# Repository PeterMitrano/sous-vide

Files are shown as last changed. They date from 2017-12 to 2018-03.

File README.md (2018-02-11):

# Sous-Vide

My first PCB design project.

### Final Results!

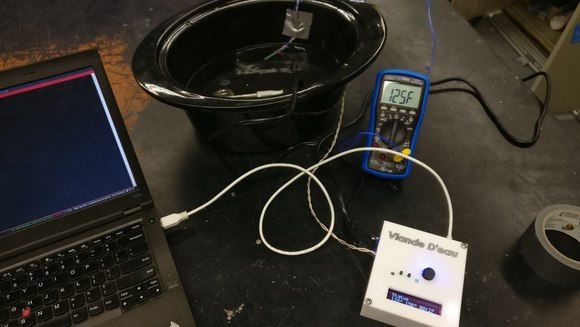
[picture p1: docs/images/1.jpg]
Tuning the temperature sensing

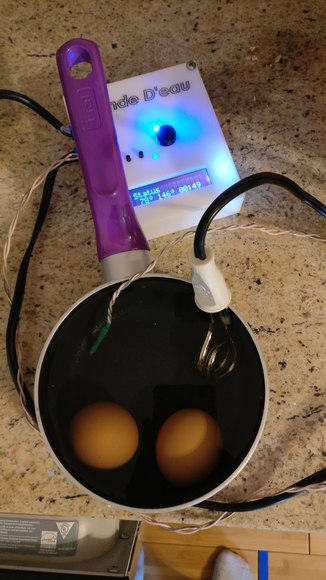
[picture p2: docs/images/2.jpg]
First Test with real food.

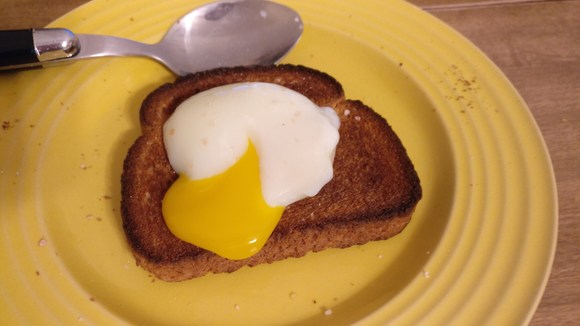
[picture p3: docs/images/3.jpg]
First Result. Perfect poached eggs!


### Materials

see [sous-vide_bom.csv](./kicad_proj/sous-vide_bom_0.3.csv)

### Schematic

see [sous-vide.sch](./kicad_proj/sous-vide.sch)

### PCB

see [sous-vide.kicad_pcb](./kicad_proj/sous-vide.kicad_pcb)

Mains power is scary. I used this to calculate trace width/clearance: http://www.desmith.net/NMdS/Electronics/TraceWidth.html

### Revision Notes

 - Hole size of screw terminals are too small. Should be 1.8542mm
 - Screw terminals are a bad idea, use IEC connector
 - Higher power heater
 - Buzzer/Dinger!
 - One wire for thermistor/heater
 - Something to stir the water around
 - Label on V+ and V- on heater are backwards (J1)
 - Button footprint is wrong

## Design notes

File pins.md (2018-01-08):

# Info on pin numbers

Arduino ESP has macros for D0-16 that map to the GPIO #

D0 -> GPIO 16 (Red LED)
D4 -> GPIO 2  (Blue LED on ESP)

### Pins I've tested with LED output

 - D0
 - D1
 - D2
 - D3
 - D4
 - D5
 - D6
 - D7
 - D8
 - RX
 - TX (no serial if you use this)
 - GPIO10 (SD3 on board)

### Pins that FAIL the LED test

 - TX, kinda because no serial
 - GPIO9, reserved for ESP
 - GPIO8, reserved for ESP
 - GPIO7, reserved for ESP
 - GPIO6, reserved for ESP

### Pins I've tested with Button Input

 - D0
 - D1
 - D2
 - D3
 - D4
 - D5
 - D6
 - D7

### Pins that FAIL the Button test

 - D8

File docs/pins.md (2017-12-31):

# Info on pin numbers

Arduino ESP has macros for D0-16 that map to the GPIO #

D0 -> GPIO 16 (Red LED)
D4 -> GPIO 2  (Blue LED on ESP)

### Pins I've tested with LED output

 - D0
 - D1
 - D2
 - D3
 - D4
 - D5
 - D6
 - D7
 - D8
 - D9 (RX on board, GPIO 3)
 - D10 (TX on board, GPIO 1, no serial if you use this)
 - GPIO10

### Pins that FAIL the LED test

 - D10, kinda because no serial
 - GPIO9, reserved for ESP
 - GPIO8, reserved for ESP
 - GPIO7, reserved for ESP
 - GPIO6, reserved for ESP

### Pins I've tested with Button Input

 - D0
 - D1
 - D2
 - D3
 - D4
 - D5
 - D6
 - D7

### Pins that FAIL the Button test

 - D8

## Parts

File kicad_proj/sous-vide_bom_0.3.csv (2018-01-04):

Component | Description | Part | References | Value | Footprint | Quantity Per PCB | Datasheet | Part # | Field8 | Field4 | Field7 | Field6 | Field5
1 | Unpolarized capacitor | C | C1 | 200nF | C_Disc_D4.3mm_W1.9mm_P5.00mm | 1
2 | Unpolarized capacitor | C | C2 | 330uF | CP_Radial_D8.0mm_P3.50mm | 1
3 | Diode | D | D1 D2 D4 | D | D_DO-35_SOD27_P7.62mm_Horizontal | 3 | https://www.fairchildsemi.com/datasheets/1N/1N914.pdf | 1N4148FS-ND
4 | LED generic | LED | D3 D5 D6 | LED | LED_D5.0mm | 3 | http://www.lumex.com/content/files/ProductAttachment/SSL-LX5093ID.pdf | 67-1105-ND
5 | Fuse, generic | Fuse | F1 | Fuse | Fuse_Holder_65600001009 | 1
6 | Generic connector, single row, 01x02 | Conn_01x02 | J3 | Conn_01x02 | Pin_Header_Straight_1x02_Pitch2.54mm | 1
7 | Generic connector, single row, 01x02 | Conn_01x02 | J1 | Heater | NC6-P108-02 | 1
8 | Generic connector, single row, 01x02 | Conn_01x02 | J4 J5 | Jumper | Pin_Header_Straight_1x02_Pitch2.54mm | 2
9 | Generic screw terminal, single row, 01x02 | Screw_Terminal_01x02 | J2 | Power | NC6-P108-02 | 1
10 | 40V Vce, 0.2A Ic, NPN, Small Signal Transistor, TO-92 | 2N3904 | Q1 | 2N3904 | TO-92_Molded_Narrow | 1 | https://www.fairchildsemi.com/datasheets/MM/MMBT3904.pdf
11 | Generic Resistor Package | RESISTOR0402 | R7 | 1.1k | R_Axial_DIN0207_L6.3mm_D2.5mm_P10.16mm_Horizontal | 1
12 | Generic Resistor Package | RESISTOR0402 | R1 | 110 | R_Axial_DIN0207_L6.3mm_D2.5mm_P10.16mm_Horizontal | 1
13 | Generic Resistor Package | RESISTOR0402 | R2 R6 | 11k | R_Axial_DIN0207_L6.3mm_D2.5mm_P10.16mm_Horizontal | 2
14 | Generic Resistor Package | RESISTOR0402 | R4 R5 | 43 | R_Axial_DIN0207_L6.3mm_D2.5mm_P10.16mm_Horizontal | 2
15 | Generic Resistor Package | RESISTOR0402 | R3 | 430 | R_Axial_DIN0207_L6.3mm_D2.5mm_P10.16mm_Horizontal | 1
16 | Push button switch, generic, symbol, four pins | SW_Push_Dual | SW1 SW2 | SW_Push_Dual | SW_TH_Tactile_Omron_B3F-10xx | 2 | http://omronfs.omron.com/en_US/ecb/products/pdf/en-b3f.pdf | SW400-ND
17 |  | G5LE | U1 | G5LE | Relay_SPDT_OMRON-G5LE-1 | 1 | https://media.digikey.com/pdf/Data%20Sheets/Omron%20PDFs/G5LE-E_G.pdf
18 |  | LCD_Backpack | U5 | LCD_Backpack | Pin_Header_Straight_1x05_Pitch2.54mm | 1
19 |  | P090S-04F20BR10K | U4 | P090S | P090S-THT_MNT | 1 | P090S-04F20BR10K |  | TT Electronics/BI | Good | None | 0.40 USD | Res Conductive Plastic POT 10K Ohm 20% 0.03W 1(Elec)/1(Mech)Turn 6mm (11.4 X 12.65 X 23mm) Pin Bracket Mount/Through ...
20 |  | RAC01 | U2 | RAC01 | RAC01-05SC | 1 | https://www.recom-power.com/pdf/Powerline-AC-DC/RAC01_02-SC.pdf
21 |  | node_mcu1.0 | U3 | node_mcu1.0 | NodeMCU_1_0 | 1
Component Groups: | 21
Component Count: | 29
Fitted Components: | 29
Number of PCBs: | 1
Total components: | 29
Schematic Version: | 0.3
Schematic Date: | 2018-01-01
BoM Date: | Thu 04 Jan 2018 14:43:18 EST
Schematic Source: | /home/peter/Projects/sous-vide/sous-vide.sch
KiCad Version: | Eeschema 4.0.7-e2-6376~58~ubuntu16.04.1

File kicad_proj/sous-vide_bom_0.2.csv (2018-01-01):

Component | Description | Part | References | Value | Footprint | Quantity Per PCB | Datasheet | Part # | Field8 | Field4 | Field7 | Field6 | Field5
1 | Unpolarized capacitor | C | C1 | C | C_Disc_D4.3mm_W1.9mm_P5.00mm | 1
2 | Diode | D | D1 D2 D4 | D | D_DO-35_SOD27_P7.62mm_Horizontal | 3 | https://www.fairchildsemi.com/datasheets/1N/1N914.pdf | 1N4148FS-ND
3 | LED generic | LED | D3 D5 D6 | LED | LED_D5.0mm | 3 | http://www.lumex.com/content/files/ProductAttachment/SSL-LX5093ID.pdf | 67-1105-ND
4 | Generic connector, single row, 01x02 | Conn_01x02 | J1 | Conn_01x02 | NC6-P108-02 | 1
5 | Generic screw terminal, single row, 01x02 | Screw_Terminal_01x02 | J2 | Conn_01x02 | NC6-P108-02 | 1
6 | Generic connector, single row, 01x02 | Conn_01x02 | J3 | Conn_01x02 | Pin_Header_Straight_1x02_Pitch2.54mm | 1
7 | 40V Vce, 0.2A Ic, NPN, Small Signal Transistor, TO-92 | 2N3904 | Q1 | 2N3904 | TO-92_Molded_Narrow | 1 | https://www.fairchildsemi.com/datasheets/MM/MMBT3904.pdf
8 | Generic Resistor Package | RESISTOR0402 | R7 | 1.1k | R_Axial_DIN0207_L6.3mm_D2.5mm_P10.16mm_Horizontal | 1
9 | Generic Resistor Package | RESISTOR0402 | R1 | 110 | R_Axial_DIN0207_L6.3mm_D2.5mm_P10.16mm_Horizontal | 1
10 | Generic Resistor Package | RESISTOR0402 | R2 R6 | 11k | R_Axial_DIN0207_L6.3mm_D2.5mm_P10.16mm_Horizontal | 2
11 | Generic Resistor Package | RESISTOR0402 | R4 R5 | 43 | R_Axial_DIN0207_L6.3mm_D2.5mm_P10.16mm_Horizontal | 2
12 | Push button switch, generic, symbol, four pins | SW_Push_Dual | SW1 SW2 | SW_Push_Dual | SW_TH_Tactile_Omron_B3F-10xx | 2 | http://omronfs.omron.com/en_US/ecb/products/pdf/en-b3f.pdf | SW400-ND
13 |  | G5LE | U1 | G5LE | Relay_SPDT_OMRON-G5LE-1 | 1 | https://media.digikey.com/pdf/Data%20Sheets/Omron%20PDFs/G5LE-E_G.pdf
14 |  | LCD_Backpack | U5 | LCD_Backpack | Pin_Header_Straight_1x05_Pitch2.54mm | 1
15 |  | P090S-04F20BR10K | U4 | P090S | P090S-THT_MNT | 1 | P090S-04F20BR10K |  | TT Electronics/BI | Good | None | 0.40 USD | Res Conductive Plastic POT 10K Ohm 20% 0.03W 1(Elec)/1(Mech)Turn 6mm (11.4 X 12.65 X 23mm) Pin Bracket Mount/Through ...
16 |  | RAC01 | U2 | RAC01 | RAC01-05SC | 1 | https://www.recom-power.com/pdf/Powerline-AC-DC/RAC01_02-SC.pdf
17 |  | node_mcu1.0 | U3 | node_mcu1.0 | NodeMCU_1_0 | 1
Component Groups: | 17
Component Count: | 24
Fitted Components: | 24
Number of PCBs: | 1
Total components: | 24
Schematic Version: | 0.2
Schematic Date: | 2017-12-28
BoM Date: | Mon 01 Jan 2018 16:54:34 EST
Schematic Source: | /home/peter/Projects/sous-vide/sous-vide.sch
KiCad Version: | Eeschema 4.0.7-e2-6376~58~ubuntu16.04.1

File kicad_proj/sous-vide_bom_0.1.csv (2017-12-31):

Component | Description | Part | References | Value | Footprint | Quantity Per PCB | Datasheet | Part # | Field8 | Field4 | Field7 | Field6 | Field5
1 | Diode | D | D3 D4 D5 | D | D_DO-35_SOD27_P7.62mm_Horizontal | 3 | https://www.fairchildsemi.com/datasheets/1N/1N914.pdf | 1N4148FS-ND
2 | LED generic | LED | D1 D2 D6 | LED | LED_D5.0mm | 3 | http://www.lumex.com/content/files/ProductAttachment/SSL-LX5093ID.pdf | 67-1105-ND
3 | Generic screw terminal, single row, 01x02 | Screw_Terminal_01x02 | J2 | Conn_01x02 | NC6-P108-02 | 1
4 | Generic connector, single row, 01x02 | Conn_01x02 | J3 | Conn_01x02 | Pin_Header_Straight_1x02_Pitch2.54mm | 1
5 | Generic connector, single row, 01x02 | Conn_01x02 | J5 | Conn_01x02 | NC6-P108-02 | 1
6 | 40V Vce, 0.2A Ic, NPN, Small Signal Transistor, TO-92 | 2N3904 | Q1 | 2N3904 | TO-92_Molded_Narrow | 1 | https://www.fairchildsemi.com/datasheets/MM/MMBT3904.pdf
7 | Generic Resistor Package | RESISTOR0402 | R8 | 110 | R_Axial_DIN0204_L3.6mm_D1.6mm_P7.62mm_Horizontal | 1
8 | Generic Resistor Package | RESISTOR0402 | R5 R7 | 11k | R_Axial_DIN0204_L3.6mm_D1.6mm_P7.62mm_Horizontal | 2
9 | Generic Resistor Package | RESISTOR0402 | R6 | 1k | R_Axial_DIN0204_L3.6mm_D1.6mm_P7.62mm_Horizontal | 1
10 | Generic Resistor Package | RESISTOR0402 | R3 R4 | 41 | R_Axial_DIN0204_L3.6mm_D1.6mm_P7.62mm_Horizontal | 2
11 | Push button switch, generic, symbol, four pins | SW_Push_Dual | SW1 SW2 | SW_Push_Dual | SW_TH_Tactile_Omron_B3F-10xx | 2 | http://omronfs.omron.com/en_US/ecb/products/pdf/en-b3f.pdf | SW400-ND
12 |  | G5LE | U3 | G5LE | Relay_SPDT_OMRON-G5LE-1 | 1 | https://media.digikey.com/pdf/Data%20Sheets/Omron%20PDFs/G5LE-E_G.pdf
13 |  | LCD_Backpack | U4 | LCD_Backpack | Pin_Header_Straight_1x05_Pitch2.54mm | 1
14 |  | P090S-04F20BR10K | U5 | P090S-04F20BR10K | TRIM_P090S-04F20BR10K | 1 | P090S-04F20BR10K |  | TT Electronics/BI | Good | None | 0.40 USD | Res Conductive Plastic POT 10K Ohm 20% 0.03W 1(Elec)/1(Mech)Turn 6mm (11.4 X 12.65 X 23mm) Pin Bracket Mount/Through ...
15 |  | RAC01 | U2 | RAC01 | RAC01-05SC | 1 | https://www.recom-power.com/pdf/Powerline-AC-DC/RAC01_02-SC.pdf
16 |  | node_mcu1.0 | U1 | node_mcu1.0 | NodeMCU_1_0 | 1
Component Groups: | 16
Component Count: | 23
Fitted Components: | 23
Number of PCBs: | 1
Total components: | 23
Schematic Version: | 0.1
Schematic Date: | 2017-12-28
BoM Date: | Sat 30 Dec 2017 17:26:24 EST
Schematic Source: | /home/peter/Projects/sous-vide/sous-vide.sch
KiCad Version: | Eeschema 4.0.7-e2-6376~58~ubuntu16.04.1

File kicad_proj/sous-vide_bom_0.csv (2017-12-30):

Component | Description | Part | References | Value | Footprint | Quantity Per PCB | Datasheet | Part # | URL
1 | Diode | D | D3 D4 D5 | D |  | 3 | https://www.fairchildsemi.com/datasheets/1N/1N914.pdf | 1N4148FS-ND
2 | LED generic | LED | D1 D2 D6 | LED |  | 3 | http://www.lumex.com/content/files/ProductAttachment/SSL-LX5093ID.pdf | 67-1105-ND
3 | Generic screw terminal, single row, 01x02 | Screw_Terminal_01x02 | J2 | Conn_01x02 |  | 1
4 | Generic connector, single row, 01x04 | Conn_01x04 | J3 | Conn_01x04 |  | 1
5 | 40V Vce, 0.2A Ic, NPN, Small Signal Transistor, TO-92 | 2N3904 | Q1 | 2N3904 | TO-92_Molded_Narrow | 1 | https://www.fairchildsemi.com/datasheets/MM/MMBT3904.pdf
6 | Generic Resistor Package | RESISTOR0402 | R3 R4 R8 | 100 | 0402 | 3
7 | Generic Resistor Package | RESISTOR0402 | R1 R2 R5 R7 | 10k | 0402 | 4 | http://www.yageo.com/documents/recent/Yageo%20LR_CFR_2013.pdf
8 | Generic Resistor Package | RESISTOR0402 | R6 | 1k | 0402 | 1
9 | Potentiometer | POT | RV1 | POT |  | 1 | http://www.vishay.com/docs/51036/p16pa16.pdf
10 | Push button switch, generic, symbol, four pins | SW_Push_Dual | SW1 SW2 | SW_Push_Dual |  | 2 | http://omronfs.omron.com/en_US/ecb/products/pdf/en-b3f.pdf | SW400-ND
11 |  | G5LE | U3 | G5LE |  | 1 | https://media.digikey.com/pdf/Data%20Sheets/Omron%20PDFs/G5LE-E_G.pdf
12 | LCD Backpack | LCD_Backpack | U4 | LCD_Backpack |  | 1 |  |  | https://www.adafruit.com/product/292
13 |  | RAC01 | U2 | RAC01 |  | 1 | https://www.recom-power.com/pdf/Powerline-AC-DC/RAC01_02-SC.pdf
14 |  | node_mcu1.0 | U1 | node_mcu1.0 |  | 1
Component Groups: | 14
Component Count: | 24
Fitted Components: | 24
Number of PCBs: | 1
Total components: | 24
Schematic Version: | 0
Schematic Date: | 2017-12-28
BoM Date: | Thu 28 Dec 2017 18:33:16 EST
Schematic Source: | /home/peter/Projects/sous-vide/sous-vide.sch
KiCad Version: | Eeschema 4.0.7-e2-6376~58~ubuntu16.04.1

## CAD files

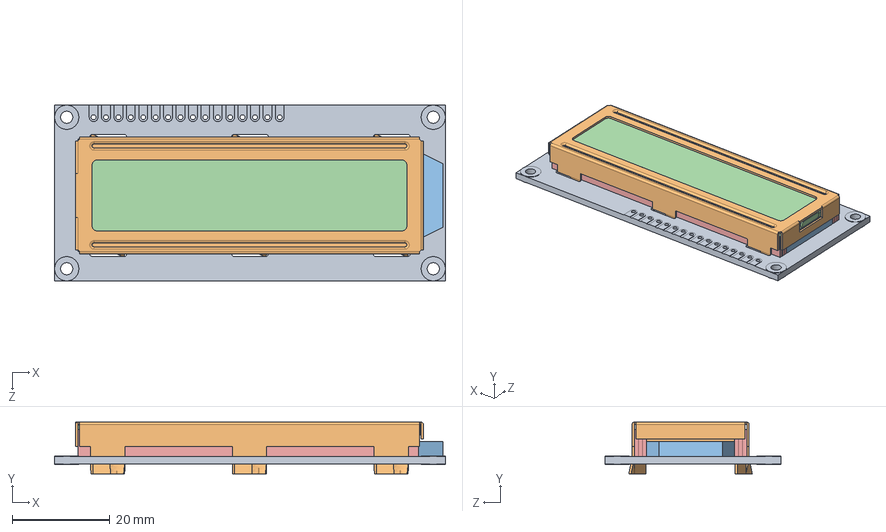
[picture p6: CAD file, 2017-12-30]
CAD/16x2_LCD_Display/DFRobot_1602_LCD.SLDASM
80.0 x 10.6 x 36.0 mm
LCD_PCB
metal_casing
LCDbacklight
LCD
conductors x 2

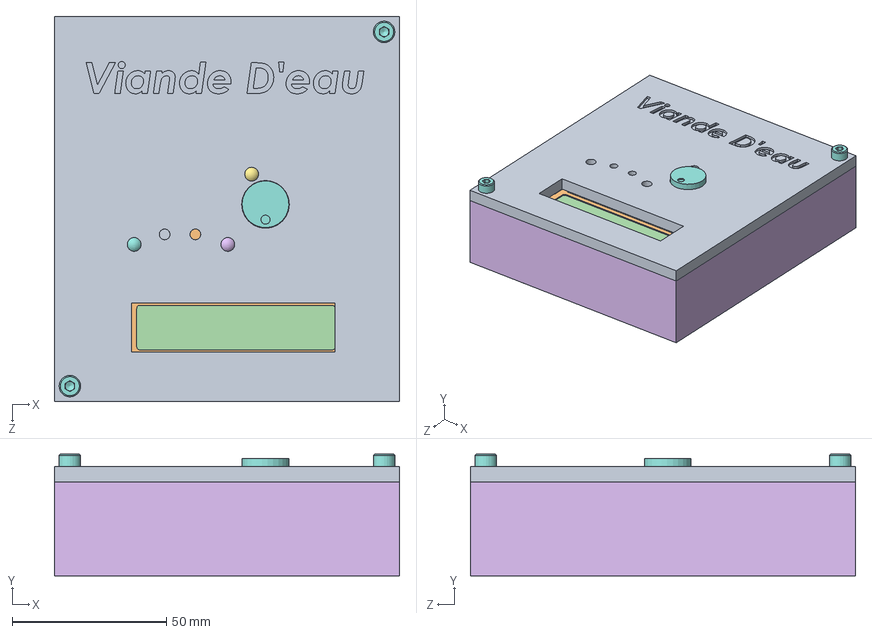
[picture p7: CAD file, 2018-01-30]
CAD/sous-vide.SLDASM
112.0 x 39.6 x 125.0 mm
LCD_PCB
metal_casing
LCDbacklight
LCD
conductors x 2
case_bottom
lcd_backpack
socket head cap screw_am x 6
case_top
Pcb
NodeMCU_1_002_
Fuse_Holder_65600001009_
RAC01-05SC_
D_DO-35_SOD27_P7.62mm_Horizontal002_
TO-92_Molded_Narrow_
LED_D5.0mm_
B3F_1002_
B3F_1002_001
Pin_Header_Straight_1x02_Pitch254mm_
D_DO-35_SOD27_P7.62mm_Horizontal002_001
D_DO-35_SOD27_P7.62mm_Horizontal002_002
LED_D5.0mm_001
LED_D5.0mm_002
Pin_Header_Straight_1x05_Pitch254mm_
R_Axial_DIN0207_L63mm_D25mm_P1016mm_Horizontal_
R_Axial_DIN0207_L63mm_D25mm_P1016mm_Horizontal_001
R_Axial_DIN0207_L63mm_D25mm_P1016mm_Horizontal_002
R_Axial_DIN0207_L63mm_D25mm_P1016mm_Horizontal_003
R_Axial_DIN0207_L63mm_D25mm_P1016mm_Horizontal_004
P090S_
C_Disc_D43mm_W19mm_P500mm_
R_Axial_DIN0207_L63mm_D25mm_P1016mm_Horizontal_005
Pin_Header_Straight_1x02_Pitch254mm_001
Pin_Header_Straight_1x02_Pitch254mm_002
nc6-p108-02_
nc6-p108-02_001
CP_Radial_D80mm_P350mm_
R_Axial_DIN0207_L63mm_D25mm_P1016mm_Horizontal_006
g5le-1-e_5dc_
fancy_knob_for_cnc
button_holder

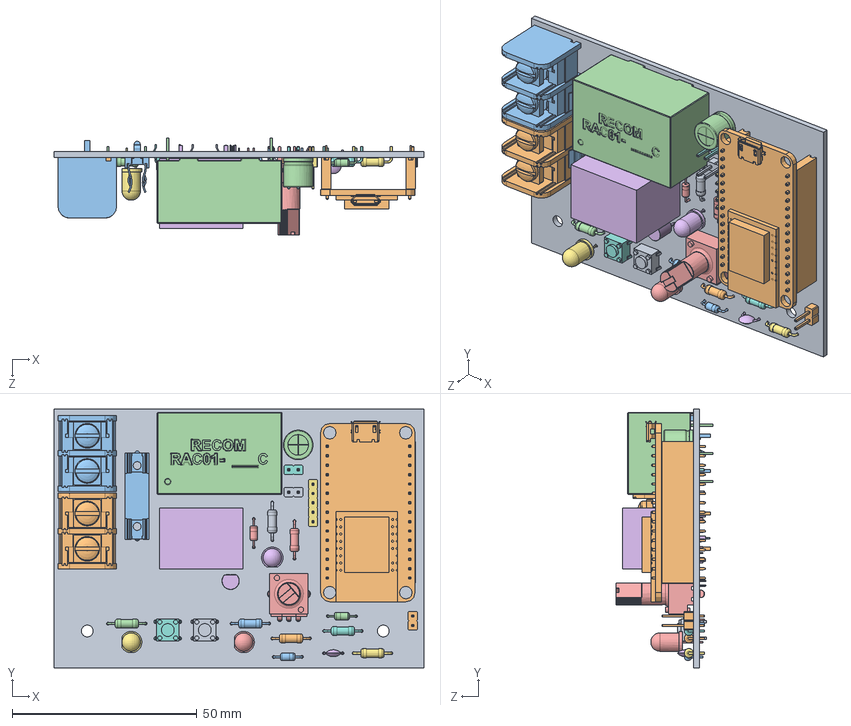
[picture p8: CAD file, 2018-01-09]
CAD/board/board.SLDASM
100.0 x 70.0 x 26.3 mm
Pcb
NodeMCU_1_002_
Fuse_Holder_65600001009_
RAC01-05SC_
D_DO-35_SOD27_P7.62mm_Horizontal002_
TO-92_Molded_Narrow_
LED_D5.0mm_
B3F_1002_
B3F_1002_001
Pin_Header_Straight_1x02_Pitch254mm_
D_DO-35_SOD27_P7.62mm_Horizontal002_001
D_DO-35_SOD27_P7.62mm_Horizontal002_002
LED_D5.0mm_001
LED_D5.0mm_002
Pin_Header_Straight_1x05_Pitch254mm_
R_Axial_DIN0207_L63mm_D25mm_P1016mm_Horizontal_
R_Axial_DIN0207_L63mm_D25mm_P1016mm_Horizontal_001
R_Axial_DIN0207_L63mm_D25mm_P1016mm_Horizontal_002
R_Axial_DIN0207_L63mm_D25mm_P1016mm_Horizontal_003
R_Axial_DIN0207_L63mm_D25mm_P1016mm_Horizontal_004
P090S_
C_Disc_D43mm_W19mm_P500mm_
R_Axial_DIN0207_L63mm_D25mm_P1016mm_Horizontal_005
Pin_Header_Straight_1x02_Pitch254mm_001
Pin_Header_Straight_1x02_Pitch254mm_002
nc6-p108-02_
nc6-p108-02_001
CP_Radial_D80mm_P350mm_
R_Axial_DIN0207_L63mm_D25mm_P1016mm_Horizontal_006
g5le-1-e_5dc_

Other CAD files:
CAD/NodeMCU/asm_pin_1.sldasm
CAD/NodeMCU/asm_pin_7.sldasm
CAD/NodeMCU/asm_pin (1) (1)_13.sldasm
CAD/NodeMCU/asm_pin (1) (1).sldasm
CAD/NodeMCU/asm_pin_3.sldasm
CAD/NodeMCU/asm_pin (1) (1)_4.sldasm
CAD/NodeMCU/asm_pin_9.sldasm
CAD/NodeMCU/asm_pin_4.sldasm
CAD/NodeMCU/asm_pin (1) (1)_14.sldasm
CAD/NodeMCU/Placa Base.sldasm
CAD/NodeMCU/asm_pin (1) (1)_2.sldasm
CAD/NodeMCU/asm_pin (1) (1)_11.sldasm
CAD/NodeMCU/asm_pin_2.sldasm
CAD/NodeMCU/asm_pin (1) (1)_12.sldasm
CAD/NodeMCU/asm_pin (1) (1)_1.sldasm
CAD/16x2_LCD_Display/LCD.SLDPRT
CAD/16x2_LCD_Display/LCD_PCB.SLDPRT
CAD/16x2_LCD_Display/LCDbacklight.SLDPRT
CAD/16x2_LCD_Display/conductors.SLDPRT
CAD/16x2_LCD_Display/metal_casing.SLDPRT
CAD/NodeMCU/Component41.sldprt
CAD/NodeMCU/Cuerpo Microprocesador v1.sldprt
CAD/NodeMCU/ESP8266 v7.SLDASM
CAD/NodeMCU/ESP8266 v7.f3d
CAD/NodeMCU/ESP8266 v7.sldprt
CAD/NodeMCU/Led RGB v4.f3d
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

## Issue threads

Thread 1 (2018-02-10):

Notes for future revisions

PeterMitrano, 2018-02-10:
- higher wattage heater
 - fix button footprints
 - better terminals to connect stuff
 - one wire for thermistor/heater
 - something to move the water
 - buzzer
 - indicate when setpoint is reached

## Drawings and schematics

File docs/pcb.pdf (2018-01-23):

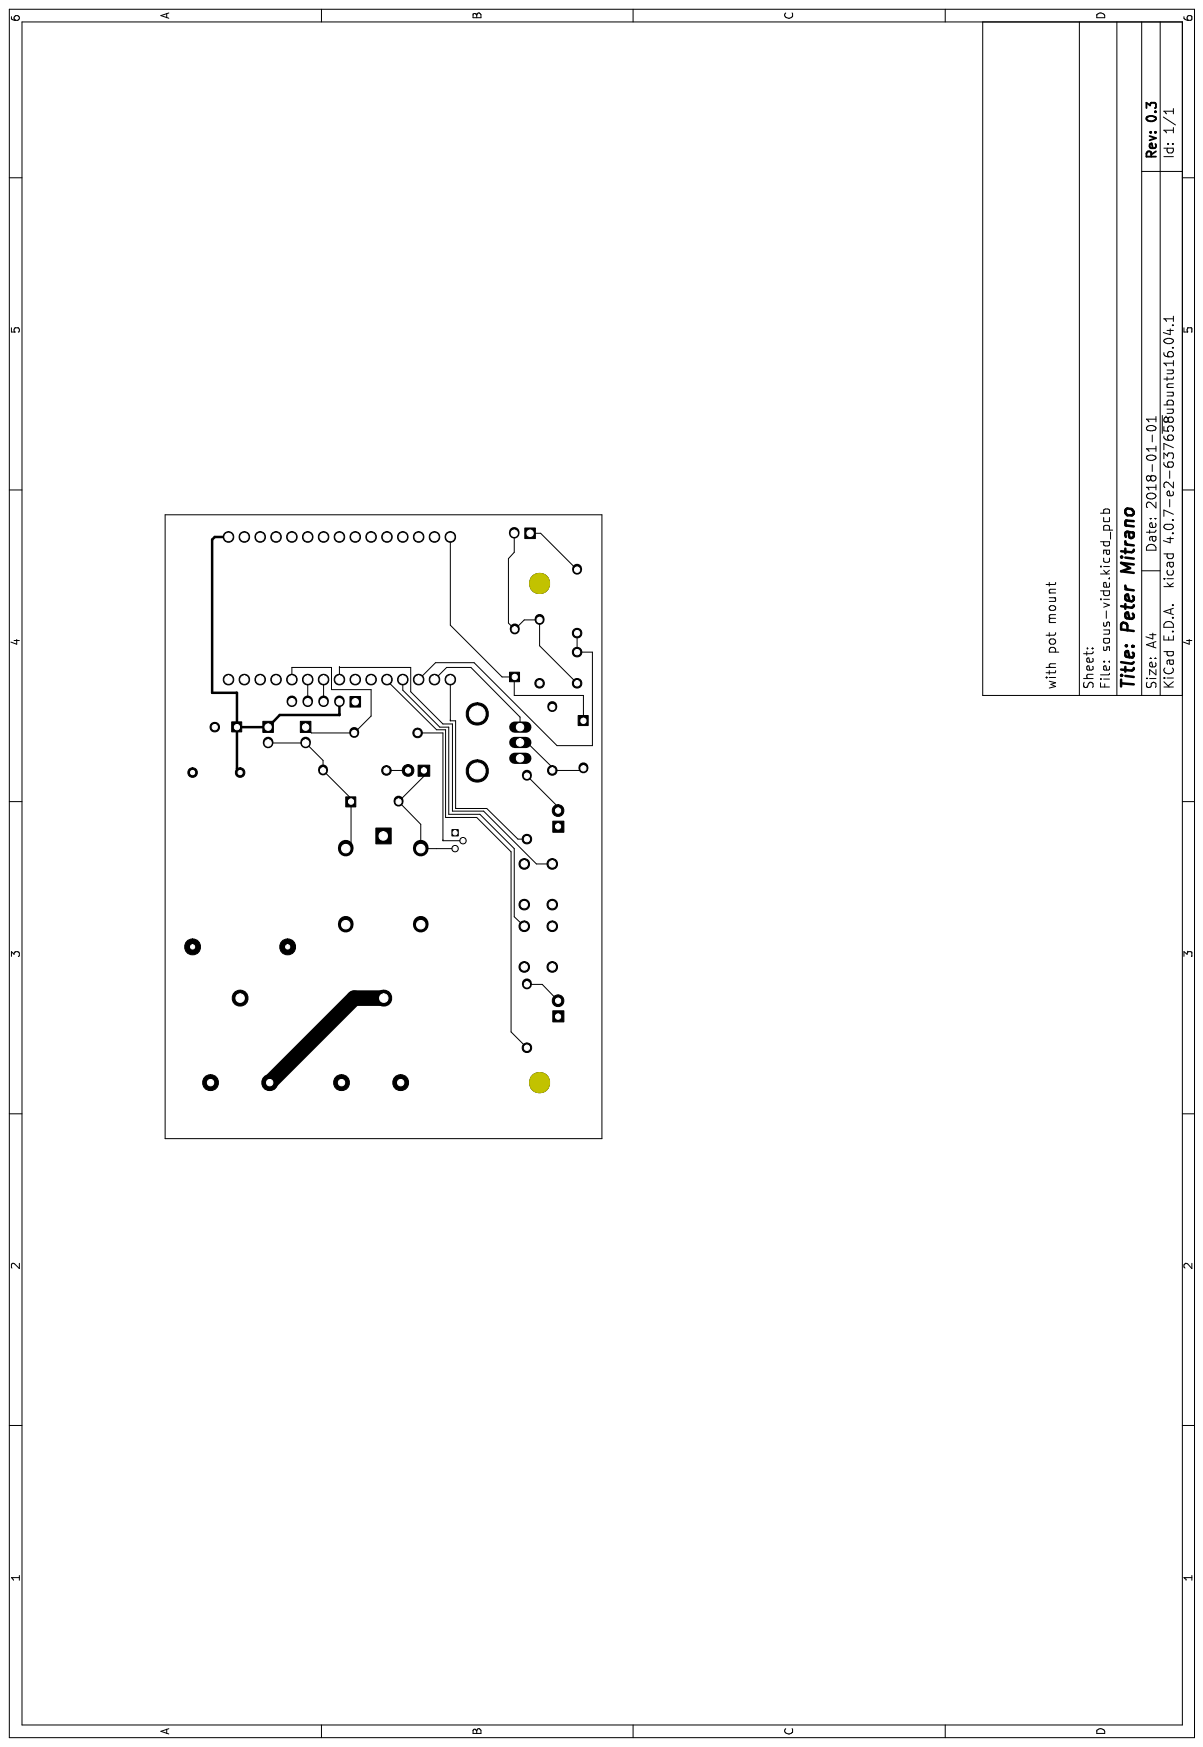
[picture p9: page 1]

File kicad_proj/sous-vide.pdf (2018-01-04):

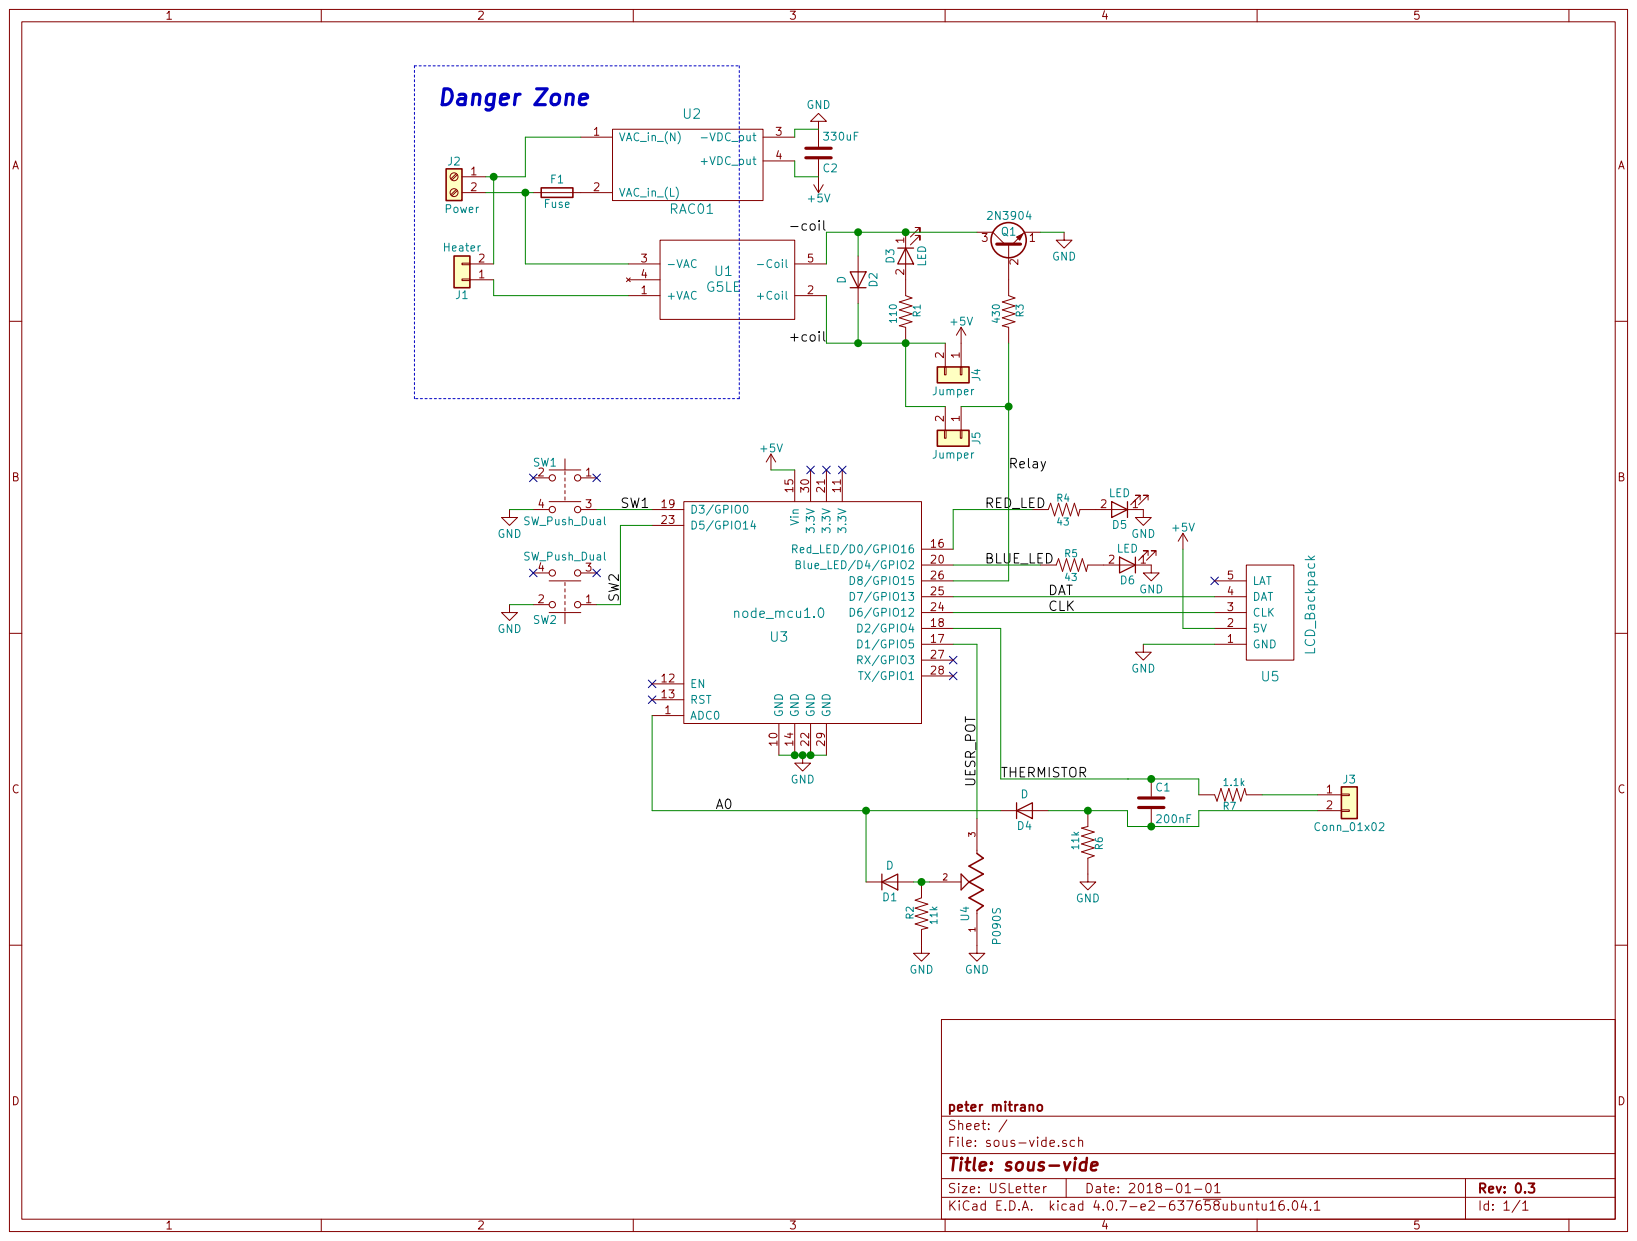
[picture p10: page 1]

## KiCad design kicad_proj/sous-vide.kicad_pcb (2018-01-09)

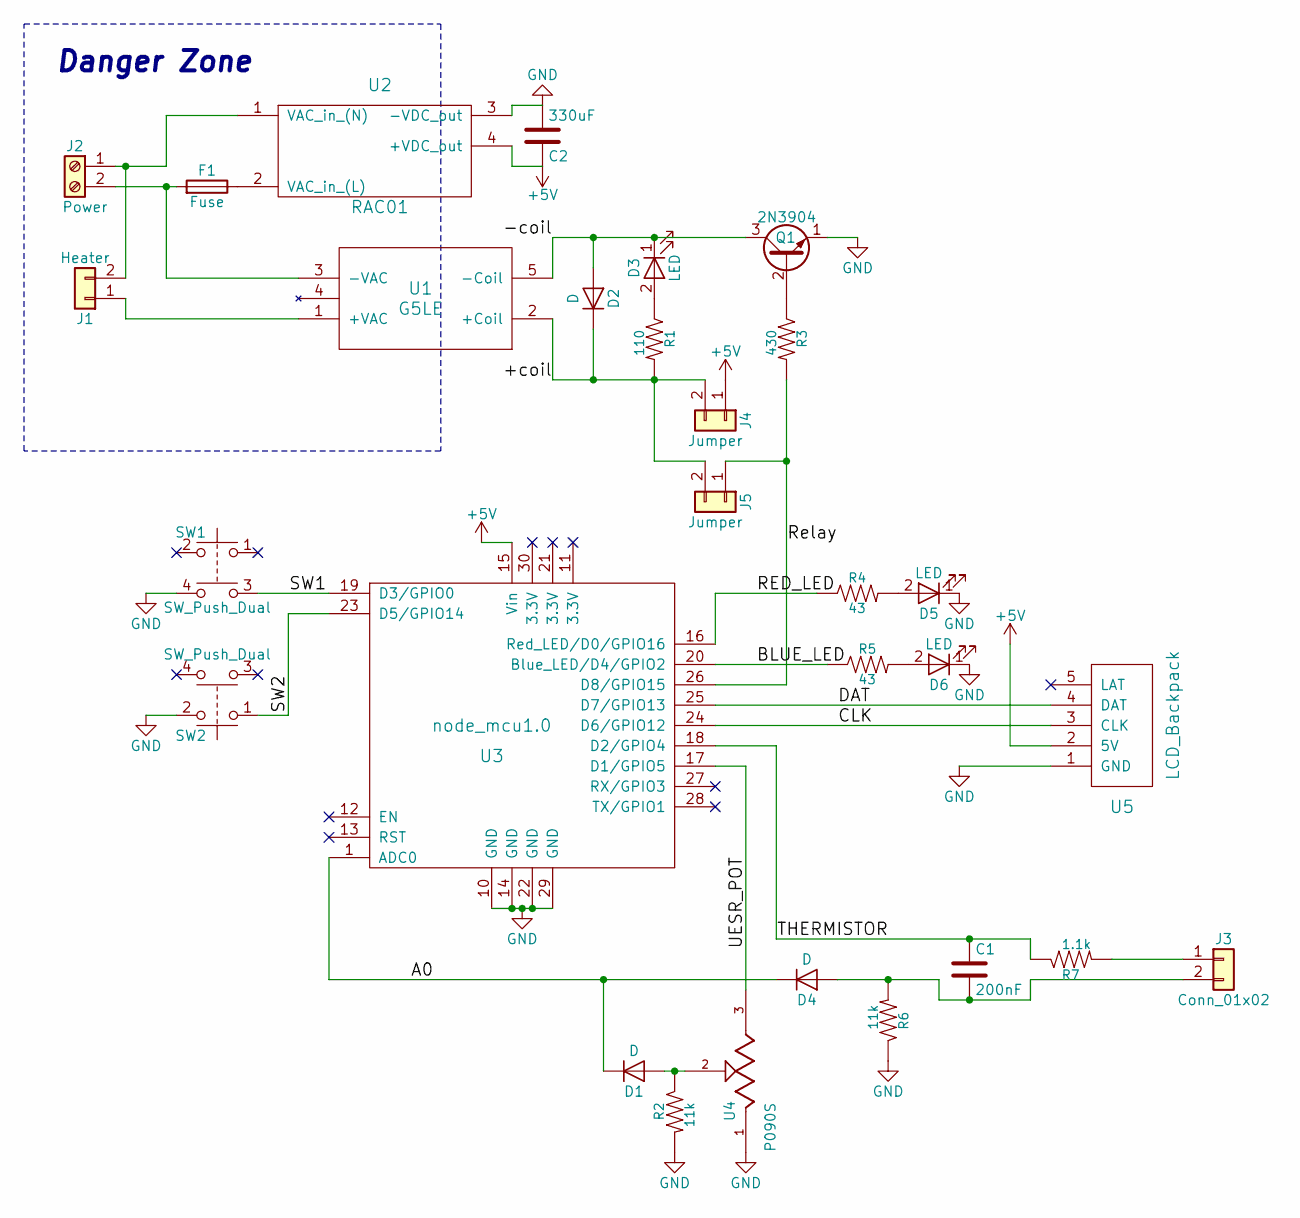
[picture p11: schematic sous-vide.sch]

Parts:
C1: 200nF; C_Disc_D4.3mm_W1.9mm_P5.00mm
C2: 330uF; CP_Radial_D8.0mm_P3.50mm
D1, D2, D4: D; D_DO-35_SOD27_P7.62mm_Horizontal; Part # 1N4148FS-ND
D3, D5, D6: LED; LED_D5.0mm; Part # 67-1105-ND
F1: Fuse; Fuse_Holder_65600001009
J1: Heater; NC6-P108-02
J2: Power; NC6-P108-02
J3: Conn_01x02; Pin_Header_Straight_1x02_Pitch2.54mm
J4, J5: Jumper; Pin_Header_Straight_1x02_Pitch2.54mm
Q1: 2N3904; TO-92_Molded_Narrow
R1: 110; R_Axial_DIN0207_L6.3mm_D2.5mm_P10.16mm_Horizontal
R2, R6: 11k; R_Axial_DIN0207_L6.3mm_D2.5mm_P10.16mm_Horizontal
R3: 430; R_Axial_DIN0207_L6.3mm_D2.5mm_P10.16mm_Horizontal
R4, R5: 43; R_Axial_DIN0207_L6.3mm_D2.5mm_P10.16mm_Horizontal
R7: 1.1k; R_Axial_DIN0207_L6.3mm_D2.5mm_P10.16mm_Horizontal
SW1, SW2: SW_Push_Dual; SW_TH_Tactile_Omron_B3F-10xx; Part # SW400-ND
U1: G5LE; Relay_SPDT_OMRON-G5LE-1
U2: RAC01; RAC01-05SC
U3: node_mcu1.0; NodeMCU_1_0
U4: P090S; P090S-THT_MNT
U5: LCD_Backpack; Pin_Header_Straight_1x05_Pitch2.54mm

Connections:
+5V: C2.1, J4.1, U2.4 (+VDC_out), U3.15 (Vin), U5.2 (5V)
/+coil: D2.1 (K), J4.2, J5.2, R1.2, U1.2 (+Coil)
/-coil: D2.2 (A), D3.1 (K), Q1.3 (C), U1.5 (-Coil)
/A0: D1.1 (K), D4.1 (K), U3.1 (ADC0)
/BLUE_LED: R5.1, U3.20 (Blue_LED/D4/GPIO2)
/CLK: U3.24 (D6/GPIO12), U5.3 (CLK)
/DAT: U3.25 (D7/GPIO13), U5.4 (DAT)
/RED_LED: R4.1, U3.16 (Red_LED/D0/GPIO16)
/Relay: J5.1, R3.2, U3.26 (D8/GPIO15)
/SW1: SW1.3, U3.19 (D3/GPIO0)
/SW2: SW2.1, U3.23 (D5/GPIO14)
/THERMISTOR: C1.1, R7.1, U3.18 (D2/GPIO4)
/UESR_POT: U3.17 (D1/GPIO5), U4.3 (CW)
GND: C2.2, D5.1 (K), D6.1 (K), Q1.1 (E), R2.2, R6.1, SW1.4, SW2.2, U2.3 (-VDC_out), U3.10 (GND), U3.14 (GND), U3.22 (GND), U3.29 (GND), U4.1 (CCW), U5.1 (GND)
unnamed: C1.2, D4.2 (A), J3.2, R6.2
unnamed: D1.2 (A), R2.1, U4.2 (S)
unnamed: D3.2 (A), R1.1
unnamed: D5.2 (A), R4.2
unnamed: D6.2 (A), R5.2
unnamed: F1.1, U2.2 (VAC_in_(L))
unnamed: F1.2, J2.2, U1.3 (-VAC)
unnamed: J1.1, U1.1 (+VAC)
unnamed: J1.2, J2.1, U2.1 (VAC_in_(N))
unnamed: J3.1, R7.2
unnamed: Q1.2 (B), R3.1

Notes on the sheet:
Danger Zone

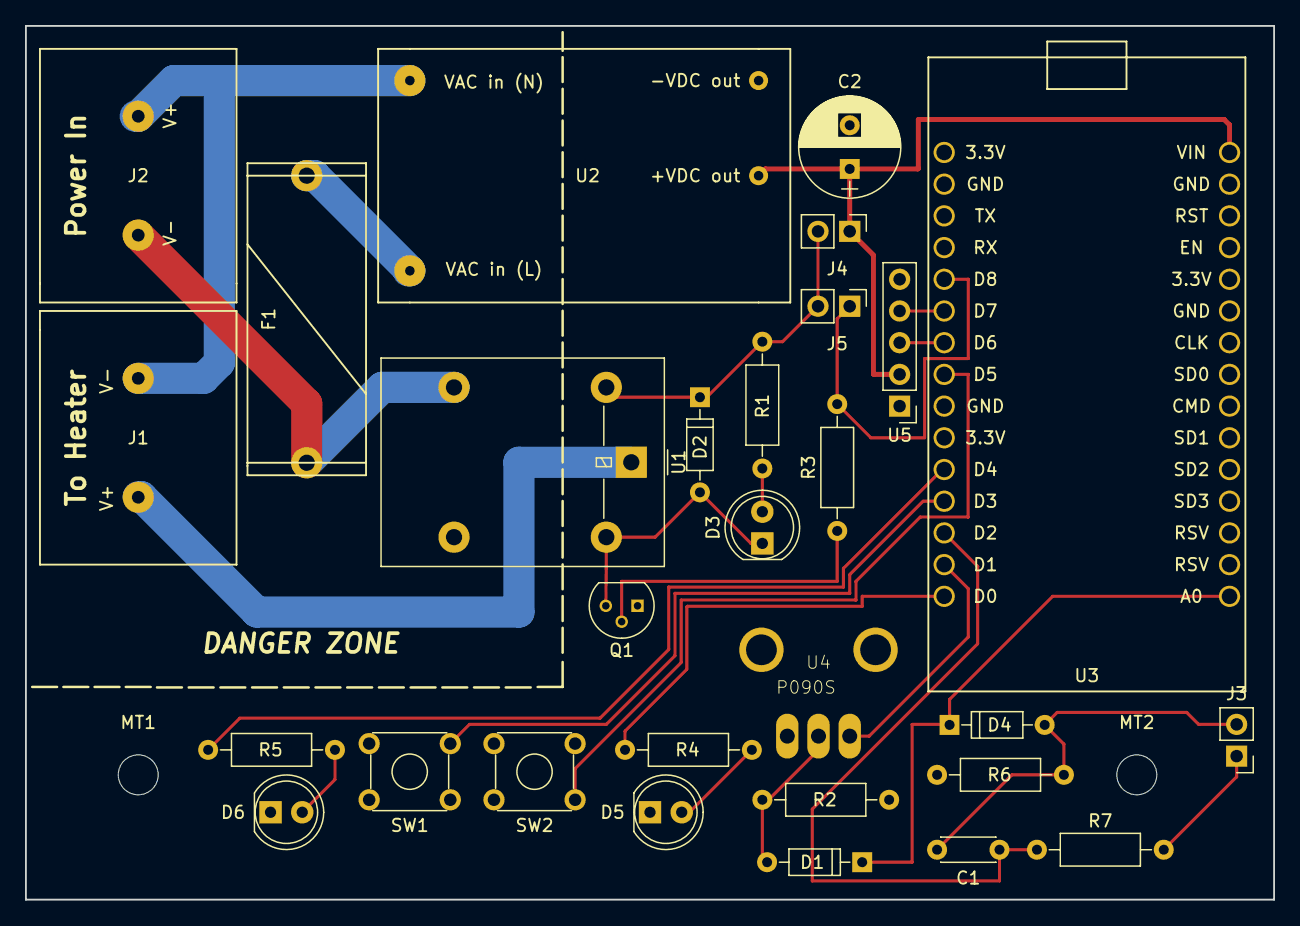
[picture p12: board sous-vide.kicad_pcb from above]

Board: 2 copper layers, 100.0 x 70.0 mm, 31 parts (0 on the bottom side), 25 nets.

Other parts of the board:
MT1, MT2: MountingHole_3.2mm_M3

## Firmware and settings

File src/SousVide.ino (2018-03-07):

#include <Arduino.h>
#include <Wire.h>
#include <queue>

#include "sous_vide.h"
#include "server.h"

// global variables
int current_temp_g = 0;
int setpoint_temp_fahrenheit_g = 0;
int time_left_sec_g = 0;
std::deque<int> temps = {};
unsigned long start_cooking_time_sec_g = 0ul;
unsigned int cooking_duration_sec_g = 0;
double duty_cycle_g = 0;
unsigned int state_g = SCAN_SSID;
Adafruit_LiquidCrystal lcd(0);
byte degree_char[8] = {0b00110, 0b01001, 0b01001, 0b00110, 0b00000, 0b00000, 0b00000, 0b00000};

ESP8266WebServer server(80);

Event checkForEvent() {
  static int sw1_c= 0;
  static int sw2_c= 0;
  static const int kDebounce = 3;
  static const int kLongPress = 9;

  bool sw1_on = !digitalRead(SW1);
  bool sw2_on = !digitalRead(SW2);

  if (sw1_on && sw1_c <= kLongPress) {
    sw1_c++;
  }
  else if (!sw1_on) {
    if (sw1_c > kLongPress) {
      Event sw1_event;
      sw1_event.type = SW1_LONG_PRESS;
      sw1_c = 0;
      return sw1_event;
    }
    else if (sw1_c > kDebounce) {
      Event sw1_event;
      sw1_event.type = SW1_PRESS;
      sw1_c = 0;
      return sw1_event;
    }
    sw1_c = 0;
  }

  if (sw2_on && sw2_c <= kLongPress) {
    sw2_c++;
  }
  else if (!sw2_on) {
    if (sw2_c > kLongPress) {
      Event sw2_event;
      sw2_event.type = SW2_LONG_PRESS;
      sw2_c = 0;
      return sw2_event;
    }
    else if (sw2_c > kDebounce) {
      Event sw2_event;
      sw2_event.type = SW2_PRESS;
      sw2_c = 0;
      return sw2_event;
    }
    sw2_c = 0;
  }

  return Event();
}

void setup() {
  pinMode(RED_LED, OUTPUT);
  pinMode(GREEN_LED, OUTPUT);
  pinMode(SW1, INPUT_PULLUP);
  pinMode(SW2, INPUT_PULLUP);
  pinMode(RELAY, OUTPUT);
  Wire.begin(DAT, CLK);
  pinMode(POT, OUTPUT);
  pinMode(THRM, OUTPUT);

  lcd.begin(16, 2);
  lcd.setBacklight(HIGH);
  lcd.createChar(0, degree_char);
  lcd.clear();

  Serial.begin(9600);

  WiFi.begin();

  lcd.setCursor(0, 0);
  lcd.print("Scanning...");

  // Try to connect to the last seen network. If it works, skip the wifi setup steps;
  WiFi.setAutoConnect(true);
  WiFi.setAutoReconnect(true);
  unsigned long start_wifi_ms = millis();
  while (!WiFi.isConnected() && millis() - start_wifi_ms < 8000) {
    delay(100);
  }

  lcd.clear();

  if (WiFi.isConnected()) {
    MDNS.begin("sous-vide");
    state_g = CHANGE_TEMP;
  }

	WiFi.mode(WIFI_STA);
	WiFi.disconnect();

  server.on("/", handleRoot);
  server.onNotFound(handleNotFound);
  server.begin();
}

void loop() {
  static unsigned long last_event_time = 0ul;
  static unsigned long last_print_time = 0ul;
  static unsigned long last_log_time_s = 0ul;
  unsigned long now_ms = millis();
  unsigned long now_s = now_ms / 1000;

  // default constructed to invalid event
  static std::queue<Event> event_queue;

  // fastest loop for reading thermistor, controlling heater, and button checking
  if (now_ms - last_event_time > 5) {
    last_event_time = now_ms;

    Event evt = checkForEvent();
    if (event_queue.empty() && evt.type != EventType::NONE) {
      event_queue.push(evt);
    }

    if (state_g == HEATING || state_g == PRE_HEATING) {
      digitalWrite(POT, LOW);
      digitalWrite(THRM, HIGH);
      unsigned int thermistor_value = analogRead(A0);
      current_temp_g = analogToTemp(thermistor_value);

      control_heater();

      // Software PWM of relay
      static unsigned long pwm_t0 = 0ul;
      static unsigned long pwm_off_time = 0ul;
      static constexpr double pwm_period_ms = 10000;
      if (now_ms - pwm_t0 >= pwm_period_ms) {
        pwm_t0 = now_ms;
        pwm_off_time = pwm_t0 + duty_cycle_g * pwm_period_ms;
      }

      digitalWrite(RELAY, now_ms <= pwm_off_time);

    }
    else {
      // make sure relay is off unless in heating state
      digitalWrite(RELAY, LOW);
    }
  }
  // run the display at a mucher slower rate
  if (now_ms - last_print_time > 100) {
    server.handleClient();

    last_print_time = now_ms;
    Event latest_evt;
    if (!event_queue.empty()) {
      latest_evt = event_queue.front();
      event_queue.pop();
    }

    static int num_ssid = 0;
    static String ssid;
    switch (state_g) {
      case SCAN_SSID:
        {
          lcd.setCursor(0, 0);
          lcd.print("Select a network:");
          lcd.setCursor(0, 1);
          lcd.print("Scanning...");
          num_ssid = WiFi.scanNetworks();
          state_g = SET_SSID;
          break;
        }
      case SET_SSID:
        {
          digitalWrite(POT, HIGH);
          digitalWrite(THRM, LOW);
          static unsigned int potentiometer_value = 0;
          potentiometer_value = 0.7 * potentiometer_value + 0.3 * analogRead(A0);
          int ssid_idx = map(potentiometer_value, 0, 1024, 0, num_ssid);

          ssid = WiFi.SSID(ssid_idx);
          char ssid_buff[16];
          snprintf(ssid_buff, 16, "%1i %-14s", ssid_idx, ssid.c_str());
          lcd.setCursor(0, 1);
          lcd.print(ssid_buff);

          if (latest_evt.type == EventType::SW1_PRESS) {
            lcd.clear();
            state_g = SET_PASSWORD;
            break;
          }
          else if (latest_evt.type == EventType::SW2_PRESS) {
            lcd.clear();
            state_g = SCAN_SSID;
            break;
          }
          break;
        }
      case SET_PASSWORD:
        {
          static int char_idx = 0;
          static char password[17];

          digitalWrite(POT, HIGH);
          digitalWrite(THRM, LOW);
          static unsigned int potentiometer_value = 0;
          potentiometer_value = 0.1 * potentiometer_value + 0.9 * analogRead(A0);
          char c = (char)map(potentiometer_value, 0, 1024, 20, 117);
          password[char_idx] = c;

          lcd.setCursor(0, 0);
          lcd.print("Enter Password");
          lcd.setCursor(0, 1);
          char password_buff[17];
          snprintf(password_buff, 17, "%-16s", password); // TODO: this is undefined behavior technically
          lcd.print(password_buff);

          if (latest_evt.type == EventType::SW1_PRESS) {
            if (char_idx < 16) {
              password[char_idx + 1] = '\0';
            }
            WiFi.begin(ssid.c_str(), (char*)password);
            WiFi.reconnect();
            lcd.clear();
            state_g = WAITING_FOR_CONNECTION;
            break;
          }
          else if (latest_evt.type == EventType::SW2_LONG_PRESS) {
            password[char_idx] = '\0';
            --char_idx;
            break;
          }
          else if (latest_evt.type == EventType::SW2_PRESS) {
            ++char_idx;
            break;
          }

          break;
        }
      case WAITING_FOR_CONNECTION:
        {
          lcd.setCursor(0, 0);
          lcd.print("Connecting...");

          if (WiFi.isConnected()) {
            String ip = WiFi.localIP().toString();

            MDNS.begin("sous-vide");

            lcd.clear();
            lcd.setCursor(0, 0);
            lcd.print("Connected");
            lcd.setCursor(0, 1);
            lcd.print(ip);

            delay(1000);

            lcd.clear();
            state_g = CHANGE_TEMP;
          }
          break;
        }
      case CHANGE_TEMP:
        {
          digitalWrite(GREEN_LED, LOW);
          digitalWrite(RED_LED, LOW);

          digitalWrite(POT, HIGH);
          digitalWrite(THRM, LOW);
          static unsigned int potentiometer_value = 0;
          potentiometer_value = 0.7 * potentiometer_value + 0.3 * analogRead(A0);
          double pot_as_temp = potToTemp(potentiometer_value);

          if (latest_evt.type == EventType::SW1_PRESS) {
            lcd.clear();
            state_g = CHANGE_TIME;
            break;
          }

          setpoint_temp_fahrenheit_g = pot_as_temp;

          lcd.setCursor(0, 0);
          lcd.print("Temp: ");
          lcd.setCursor(0, 1);
          lcd.print(formatTemp(setpoint_temp_fahrenheit_g));
          lcd.write((uint8_t)0);
          break;
        }

      case CHANGE_TIME:
        {
          digitalWrite(GREEN_LED, LOW);
          digitalWrite(RED_LED, LOW);

          digitalWrite(POT, HIGH);
          digitalWrite(THRM, LOW);
          static unsigned int potentiometer_value = 0;
          potentiometer_value = 0.7 * potentiometer_value + 0.3 * analogRead(A0);

          if (latest_evt.type == EventType::SW1_PRESS) {
            lcd.clear();
            state_g = PRE_HEATING;
            break;
          }
          else if (latest_evt.type == EventType::SW2_PRESS) {
            lcd.clear();
            state_g = CHANGE_TEMP;
            break;
          }

          cooking_duration_sec_g = potToTime(potentiometer_value);
          lcd.setCursor(0, 0);
          lcd.print("Time: ");
          lcd.setCursor(0, 1);
          lcd.print(formatTime(cooking_duration_sec_g));
          break;
        }

      case PRE_HEATING:
        {
          static bool at_temp = false;
          if (current_temp_g >= setpoint_temp_fahrenheit_g || at_temp) {
            at_temp = true;
            lcd.clear();
            start_cooking_time_sec_g = now_s;
            state_g = HEATING;
            break;
          }
          else {
            static unsigned long last_blink_ms = now_ms;
            static bool blink_state = true;

            if (now_ms - last_blink_ms > 1000) {
              blink_state = !blink_state;
              last_blink_ms = now_ms;
            }

            digitalWrite(GREEN_LED, LOW);
            digitalWrite(RED_LED, blink_state);


            lcd.setCursor(0, 0);
            lcd.print("Pre-Heating");
          }

          lcd.setCursor(0, 1);
          lcd.print(formatTemp(current_temp_g));
          lcd.write(0);
          lcd.print(" ");
          lcd.print(formatTemp(setpoint_temp_fahrenheit_g));

          break;
        }
      case HEATING:
        {
          digitalWrite(GREEN_LED, LOW);
          digitalWrite(RED_LED, HIGH);
          if (latest_evt.type == EventType::SW2_PRESS) {
            lcd.clear();
            state_g = PAUSED;
            break;
          }

          time_left_sec_g = cooking_duration_sec_g - (now_s - start_cooking_time_sec_g);
          if (time_left_sec_g == 0) {
            lcd.clear();
            state_g = FINISHED;
            break;
          }

          lcd.setCursor(0, 0);
          lcd.print("Status");
          lcd.setCursor(0, 1);
          lcd.print(formatTemp(current_temp_g));
          lcd.write(0);
          lcd.print(" ");
          lcd.print(formatTemp(setpoint_temp_fahrenheit_g));
          lcd.write(0);
          lcd.print(" ");
          lcd.print(formatTime(time_left_sec_g));
          break;
        }

      case PAUSED:
        {
          digitalWrite(GREEN_LED, LOW);
          digitalWrite(RED_LED, HIGH);
          if (latest_evt.type == EventType::SW1_PRESS) {
            lcd.clear();
            state_g = HEATING;
            break;
          }
          else if (latest_evt.type == EventType::SW2_PRESS) {
            lcd.clear();
            state_g = FINISHED;
            break;
          }

          lcd.setCursor(0, 0);
          lcd.print("paused.");
          break;
        }

      case FINISHED:
        lcd.setCursor(0, 0);
        lcd.print("Finished.");
        lcd.setCursor(0, 1);
        lcd.print("Enjoy!");
        // [[fallthrough]]
      default:
        digitalWrite(GREEN_LED, LOW);
        digitalWrite(RED_LED, LOW);
        break;
    }
  }

  static unsigned int head = 0u;
  if (now_s - last_log_time_s > 30) {
    last_log_time_s = now_s;
    if (state_g == PRE_HEATING || state_g == HEATING) {
      temps.push_back(current_temp_g);
      if (temps.size() > 1000) {
        temps.pop_front();
      }
    }
  }
}


double analogToTemp(const unsigned int thermistor_value) {
  //static constexpr int ADC_TOP = 1023;
  //static constexpr int BETA = 3977;
  //static constexpr double LNA = -4.12858298874828;
  //static constexpr int R_REF = 1100;
  //double temp = (R_REF * thermistor_value) / (ADC_TOP - thermistor_value);
  //temp = BETA / (log(temp) - LNA);
  //temp = temp - 273.15;

  // FIXME: this is empirically derived from a set of data points
  double temp = exp((thermistor_value + 1220) / 382.7);
  return temp;
}

double potToTemp(const unsigned int potentiometer_value) {
  static constexpr int minimum_temp = 120; // degrees F
  static constexpr int maximum_temp = 190; // degrees F
  return map(potentiometer_value, 3, 938, minimum_temp, maximum_temp);
}

unsigned int potToTime(const unsigned int potentiometer_value) {
  static constexpr unsigned int minimum_time = 30; // X minutes
  static constexpr unsigned int maximum_time = 24 * 60; // X hours
  static constexpr unsigned int minimum_pot = 3;
  static constexpr unsigned int maximum_pot = 930;
  const unsigned int constrained_pot_value = max(min(potentiometer_value, maximum_pot), minimum_pot);
  const double a = (maximum_time - minimum_time) / (pow(maximum_pot,2) - 2.0*minimum_pot*maximum_pot);
  const double b = -2*a*minimum_pot;
  int time_minutes = (a*pow(constrained_pot_value, 2) + b*constrained_pot_value + minimum_time);

  if (time_minutes > 12*60) {
    time_minutes -= time_minutes % 60;
  }
  else if (time_minutes > 6*60) {
    time_minutes -= time_minutes % 30;
  }
  else if (time_minutes > 60) {
    time_minutes -= time_minutes % 15;
  }

  return time_minutes * 60;
}

String formatTime(const unsigned long t_s) {
  unsigned long min = (t_s / 60) % 60;
  unsigned long h = t_s / 3600;
  String hr_str("00");
  if (h < 10) {
    hr_str[1] = String(h)[0];
  }
  else {
    hr_str = String(h);
  }

  String min_str("00");
  if (min < 10) {
    min_str[1] = String(min)[0];
  }
  else {
    min_str = String(min);
  }
  return hr_str + String(":") + min_str;
}

String formatTemp(const unsigned int temp_fahrenheit) {
  String temp(temp_fahrenheit);
  if (temp_fahrenheit < 10) {
    temp = String("  ") + temp;
  }
  else if (temp_fahrenheit < 100) {
    temp = String(" ") + temp;
  }

  return temp;
}

void control_heater() {
  static constexpr double kP = 0.18;
  static constexpr double kI = 0.0001;
  static constexpr double kFF = 0.0018;
  static double integral = 0;

  double error = setpoint_temp_fahrenheit_g - current_temp_g;

  static double last_error = error;

  if (error > -2) {
    integral += error;

    if ((error > 0 && last_error < 0) || (error < 0 && last_error > 0)) {
      integral = 0;
    }

    double derivative = error - last_error;
    duty_cycle_g = kP * error + kI * integral + kFF * setpoint_temp_fahrenheit_g;

    // enforce limit on duty cycle
    duty_cycle_g = fmax(fmin(duty_cycle_g, 1.f), 0.f);

    last_error = error;

#ifdef DEBUG
  Serial.print(integral);
  Serial.print(", ");
  Serial.println(duty_cycle_g);
#endif
  }
  else {
    duty_cycle_g = 0;
  }
}

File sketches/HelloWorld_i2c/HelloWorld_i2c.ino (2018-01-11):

/*
 Demonstration sketch for Adafruit i2c/SPI LCD backpack
 using MCP23008 I2C expander
 ( http://www.ladyada.net/products/i2cspilcdbackpack/index.html )

 This sketch prints "Hello World!" to the LCD
 and shows the time.
 
  The circuit:
 * 5V to Arduino 5V pin
 * GND to Arduino GND pin
 * CLK to Analog #5
 * DAT to Analog #4
*/

// include the library code:
#include "Wire.h"
#include "Adafruit_LiquidCrystal.h"

// Connect via i2c, default address #0 (A0-A2 not jumpered)
Adafruit_LiquidCrystal lcd(0);

void setup() {
  // set up the LCD's number of rows and columns:
  Wire.begin(D7, D6);
  lcd.begin(16, 2);
  lcd.clear();
  // Print a message to the LCD.
  lcd.setCursor(0, 0);
  lcd.print("hello");
}

void loop() {
  // set the cursor to column 0, line 1
  // (note: line 1 is the second row, since counting begins with 0):
  lcd.setCursor(0, 1);
  // print the number of seconds since reset:
  lcd.print(millis() / 1000);

  lcd.setBacklight(HIGH);
//  delay(500);
//  lcd.setBacklight(LOW);
//  delay(500);
}

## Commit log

2017-12-30 git init
    v0.1 done!
    haven't verified any of this works but the board is "done"
    [digikey_cart.csv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]
2017-12-30 added correct potentiometer footprint
    [sous-vide-B.Cu.gbl, sous-vide-B.Mask.gbs, sous-vide-B.SilkS.gbo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]
2017-12-30 add freecad + step
    [sous-vide.step, sous_vide.FCStd]
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2017-12-30 started testing pins for GPIO
    [sous-vide.sch, sous_vide.FCStd]
2017-12-31 redo entire schematic and layout
    now complete with danger zone!
    [sous-vide.kicad_pcb, sous-vide.sch, sous-vide_bom_0.1.csv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]
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2017-12-31 fix DRC issues
    [sous-vide.kicad_pcb, sous-vide.sch]
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2017-12-31 fix resistor footprints
    - add dashed line
    - fix pot to use through hole mounting
    - checked everything for footprint errors
    [sous-vide.kicad_pcb, sous-vide.sch]
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2017-12-31 add filter capacitor to thermistor
    [sous-vide-B.Cu.gbl, sous-vide-B.Mask.gbs, sous-vide-B.SilkS.gbo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]
2017-12-31 tested analog-multiplexor circuit
    - it works!
    [sous-vide.kicad_pcb]
2018-01-01 thermistor test "works"
    - if I understand correctly, R_Ref is calculated to be 1.1k
    - works for the one sample (Temp, ADC) I have
    - removed the 1k resistor on the relay circuit
    [sous-vide-B.Cu.gbl, sous-vide-B.Mask.gbs, sous-vide-B.SilkS.gbo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]
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2018-01-02 V 0.3
    - added protection circuit and fuse
    - fixed LED indicator on relay circuit with Jeff's help
    [sous-vide-B.Cu.gbl, sous-vide-B.Mask.gbs, sous-vide-B.SilkS.gbo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]
2018-01-02 fix power circuit
    - reroute
    - make board slightly bigger
    [sous-vide-B.Cu.gbl, sous-vide-B.Mask.gbs, sous-vide-B.SilkS.gbo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]
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2018-01-02 breadboarded everything I could and tested
    - did not test I2C or Power Supply
    - relay state effects analog readings. bad!
    [sous-vide.sch]
2018-01-02 new schematic using NC7SB analog multiplexer
    - requires surface mount :(
    - re-annotated everything so routing will be very annoying
    Also, I was testing to see why/how relay load affected analog readings
    and I discovered a few odd things:
    - D4/GPIO2/Blue_LED does not light up. low voltage?
    - using a transistor on *just* the pot (instead of GPIO directly)
    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
    [sous-vide-B.Cu.gbl, sous-vide-B.Mask.gbs, sous-vide-B.SilkS.gbo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]
2018-01-04 Fix analog multiplex logic
    - tested with multimeter and oscilloscope and everything looks good
    - tested power supply, and it actually gives ~5.6 volts. This is fine
    fine for the MCU. Have to check if it's ok for the LCD
    - power supply powers the board successfully!
    - earlier issues were due to ground/power lines not connecting across
    the second half of the breadboard
    [SousVide.ino]
2018-01-04 reverted to dio multiplexor because it works
    - measure 67mA on the coil, 5.31mA on the DIO
    [sous-vide.sch]
2018-01-04 regenerated and saved everything
    - no changes to pcb
    - generated gerber files, drill file, schematic and BOM
    [sous-vide.kicad_pcb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]
2018-01-04 added all pin labels to nodemcu footprint
    - add helpful labels on back
    [sous-vide.kicad_pcb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]
2018-01-04 rerouted wires so there are no breaks in the ground plane
    [sous-vide.kicad_pcb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]
2018-01-04 everything has been ordered!
    [digikey_cart_2.csv]
2018-01-04 regenerated circuit board STEP
    [sous-vide.step, sous_vide.FCStd]
2018-01-04 remove STEP file cuz it's big
    [sous-vide.step]
2018-01-04 added sous-vide via git(hub) LFS
    [sous-vide.step]
2018-01-05 now trying STL
    solidworks still dying
    [sous-vide.stl]
2018-01-05 redid the case bottom
    - started work on case top but that might change so I'm not fussing
    [NC6-P108-02.SLDPRT, User Library-P090S-topadjust.SLDPRT, case_bottom.SLDPRT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]
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2018-01-05 remove old CAD formats
    [Pcb.sldprt, sous-vide.step, sous_vide.FCStd]
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2018-01-05 more project cleanup
    - no idea if I just broke the kicad project
    [digikey_cart.csv, digikey_cart_2.csv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]
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2018-01-09 update to reflect final LED/pot positions
    - had to make the pot smaller because it conflicts with relay LED :(
    [NC6-P108-02.SLDPRT, case_top.SLDPRT, fancy_knob.SLDPRT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]
2018-01-09 figured out how to use kicad stepup properly
    - demo for omron b3f_1000 button works perfectly!
    - just make/find STEP, load pcb footprint in freecad, align STEP with
    footprint, export WRL and STEP to the right folder (either in custom
    *.pretty library or in /usr/share/kicad/modules/packages3d/*.pretty
    library)
    - 3d preview in kicad will now work
    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
    [B3F_1000.fcstd, B3F_1000.step]
2018-01-09 regenerated b3f for consistency and added relay g5le
    [B3F_1000.fcstd, B3F_1000.step, G5LE_1_E.fcstd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]
2018-01-09 add screw terminals 3d
    [NC6-P108-02.fcstd, sous-vide.kicad_pcb]
2018-01-09 apparently we also need the *1 files
    [B3F_1000.fcstd, G5LE_1_E.fcstd, NC6-P108-02.fcstd]
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2018-01-09 generated board to test progress
    - still missinged Diodes, LEDs, Resistors, Transistor
    - didn't do NodeMCU yet either
    [sous-vide.step, sous_vide.FCStd]
2018-01-09 regenerated whole board
    - everything in kicad viewer now shows up in freecad/step
    - still need to add STEP for NodeMCU and potentiometer
    - also may have lost my pot footprint among other things
    [sous-vide.kicad_pcb, sous-vide.step, sous_vide.FCStd]
2018-01-09 remove the libraries I deleted
    - schemtaics/footprints are cached thankfully
    - still step files for fuse, node mcu, pot
    [sous-vide.kicad_pcb]
2018-01-09 add steps from tracepartsonline.net
    - removed unecessary renderings
    [52931.stp, User Library-LED5MM.SLDPRT, g5le-1-e_5dc.stp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]
2018-01-09 add nodemcu 3d
    - also add p090s step
    [NodeMCU.fcstd, NodeMCU.step, P090S.step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]
2018-01-09 done added 3d models for v0.3
    [Fuse_Holder_65600001009.fcstd, P090S.fcstd, P090S.step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]
2018-01-09 all parts now in 3d step!
    [T0-92_Molded_Narrow.stp, sous-vide.kicad_pcb, sous-vide.step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]
2018-01-09 imported new step cad into solidworks successfully
    - some small errors imported surface that I can easily fix
    - aslo added step for node mcu that I think is more accurate
    [B3F_1002_.sldprt, B3F_1002_001.sldprt, CP_Radial_D80mm_P350mm_.sldprt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]
2018-01-09 healed all bad surfaces
    [LED_D5.0mm_.sldprt, LED_D5.0mm_001.sldprt, LED_D5.0mm_002.sldprt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]
2018-01-09 reorganized cad files and deleted unecessary old files
    [61301411821.SLDASM, 61301411821_01.SLDPRT, 61301411821_02.SLDPRT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]
2018-01-09 updated full case asm to use new board
    - looks amazing
    - still need to go back and fix node mcu model
    [board.SLDASM, button_contact.SLDPRT, case_top.SLDPRT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]
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2018-01-11 add STLs and fix backpack model
    - backapck is now more accurate to physical object
    [case_bottom.STL, case_top.STL, lcd_backpack.SLDPRT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]
2018-01-12 update parts for better tolerances
    [case_bottom.SLDPRT, case_bottom.STL, case_top.SLDPRT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]
2018-01-23 testing with the board
    - documenting the issues/bugs
    [SousVide.ino]
2018-01-23 fixed relay testing
    - runs at 50% duty cycle (1s period)
    - water heats up and nothing explodes
    - time/temp settings still need work
    - still no plans for thermistor yet
    - ned to reprint all the parts, consider laser cut top
    [SousVide.ino]
2018-01-24 add 3d printable knob
    [fancy_knob_for_printing.SLDPRT, fancy_knob_for_printing.STL]
2018-01-25 redo CAD
    - ready for laser cutting top
    - reprint bottom
    - CNC mill the knob for extra fanciness
    [case_bottom.SLDPRT, case_top.DXF, case_top.SLDPRT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]
2018-01-25 case bottom updates -> STL
    [case_bottom.SLDPRT, case_bottom.STL]
2018-01-25 fix time/temp formatting
    - increase min/max cooking duration
    - lcd.clear() does not work?
    [SousVide.ino, sous_vide.h]
2018-01-25 fix timing
    - add units to clarify
    - turns out code is slow and loop time is ~50ms
    [SousVide.ino]
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2018-01-29 derived formula from data and put it in code
    - the physics based formula doesn't make any sense on my real data
    [SousVide.ino]
2018-01-29 fix holes to power terminals
    - also make a few things thicker
    [case_bottom.SLDPRT, case_bottom.STL, sous-vide.SLDASM]
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2018-01-29 updated button holder again
    [button_holder.SLDPRT, button_holder.STL, case_top.dwg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]
2018-01-30 updates to 3d models
    - wider 3d printed knob
    - more curves/thicker stuff in base
    [case_bottom.SLDPRT, case_top.DXF, case_top.SLDPRT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]
2018-01-30 add stl for case bottom v3
    [case_bottom.STL]
2018-02-04 turns out I got the thermistor circuit wrong
    so I updated the schematic even though I'm definitely not ordering a new board just for that.
    [sous-vide.sch]
2018-02-04 reworked event handling
    - less frequenty updates of LCD
    - fast loop rate for buttons/heater control
    [SousVide.ino, sous_vide.h]
2018-02-04 small param tweaks
    - fix wrapping error
    [SousVide.ino, sous_vide.h]
2018-02-10 First test went ok, eggs were too hard boiled
    - added integral resetting
    [SousVide.ino]
2018-02-10 fixed end condition
    TODO:
    - should include a "add more time" option?
    - INTERNET!!!!
    [SousVide.ino]
2018-02-11 This shit actually works!
    - revert minimimu time change
    [SousVide.ino]
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2018-03-04 add selection of wifi from menu
    - remembers wifi on reboot
    [SousVide.ino, sous_vide.h]
2018-03-04 untested 'fixes' to mdns
    - remove hardcoded password
    - lower P gain a bit
    [SousVide.ino]
2018-03-07 revert temp constants
    - checked against real digital thermometer and it was saying 150 when
    it was 165
    [temperature_data.ods]
